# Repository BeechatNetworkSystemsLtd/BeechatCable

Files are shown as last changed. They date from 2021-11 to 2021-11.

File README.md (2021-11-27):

# Beechat Use-&-Charge cable
## _Flexible cable that allows charging your smartphone while using the Beechat Clip_

BNSLTD

General
-------------------

The cable is a UFP (Upstream Facing Port) to DFP (Downstream Facing Port) device, for mobile device charging and data transmission, the DFP port is configured with a 10K resistor between the DC and Vbus pin of the USB-C male plug, which allows a current delivery of up to 3A for devices that require it, the UFP port is designed on a PCB (Printed circuit board), which has the functionality of connecting two FFC (Flexible flat cable) cables, for the transmission of power to the USB-C MALE, also in this design, we have two data transmission lines between the 2 FFC cables, to send and receive data between devices.

Repository content:
-------------------
- Hardware - all Eagle design files (.brd, .sch)
- Production- Gerber files.

Images:
-------------------

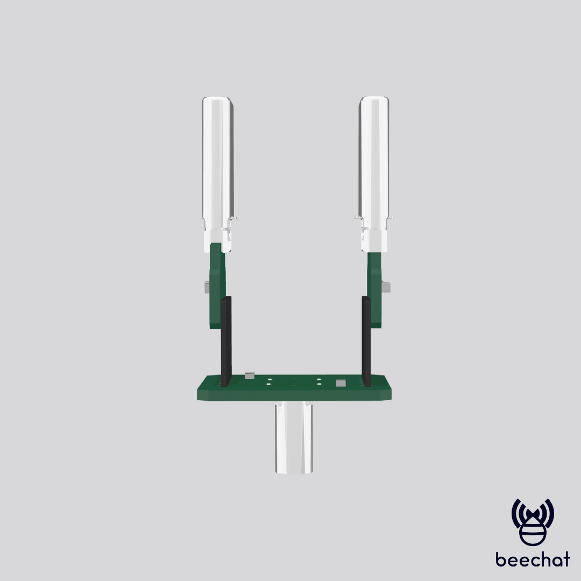
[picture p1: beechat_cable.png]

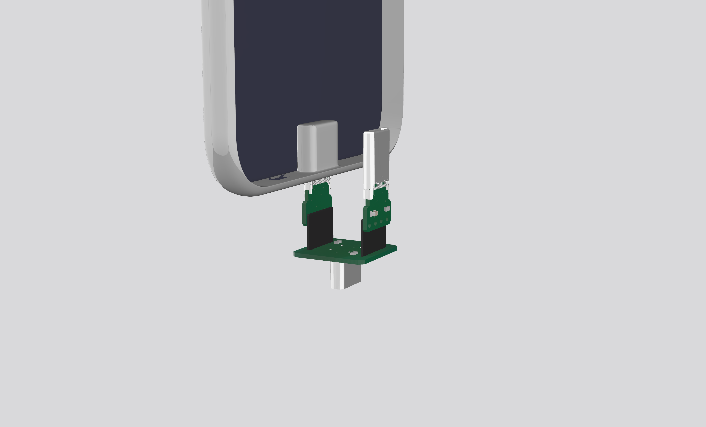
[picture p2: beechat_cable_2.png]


PCB USB-C FEMALE features
-------------------
* **Dimensions:** 14 * 14mm
* **DC resistors:** 5.1 k
* **4-position FFC cable connection pins. (x2)**
* **USB C male receptable connector** 5V (USB)
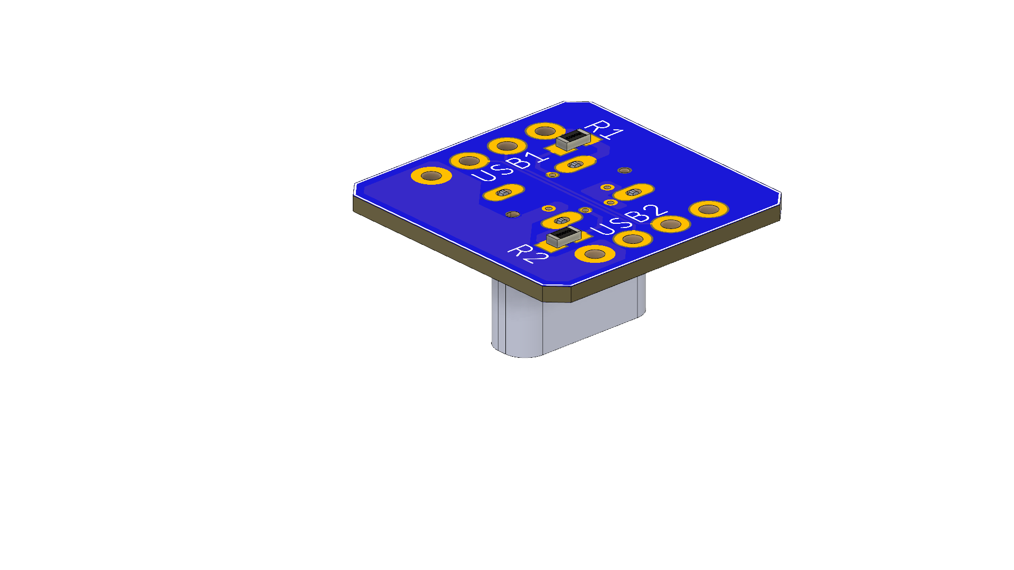
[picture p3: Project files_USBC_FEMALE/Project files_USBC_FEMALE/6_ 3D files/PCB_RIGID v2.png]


PCB USB C MALE features
-------------------
* **Dimensions:** 9.5 * 4mm
* **DC resistor:** 10k
* **4-position FFC cable connection pins. (x1)**
* **USB C Female plug Slim.**
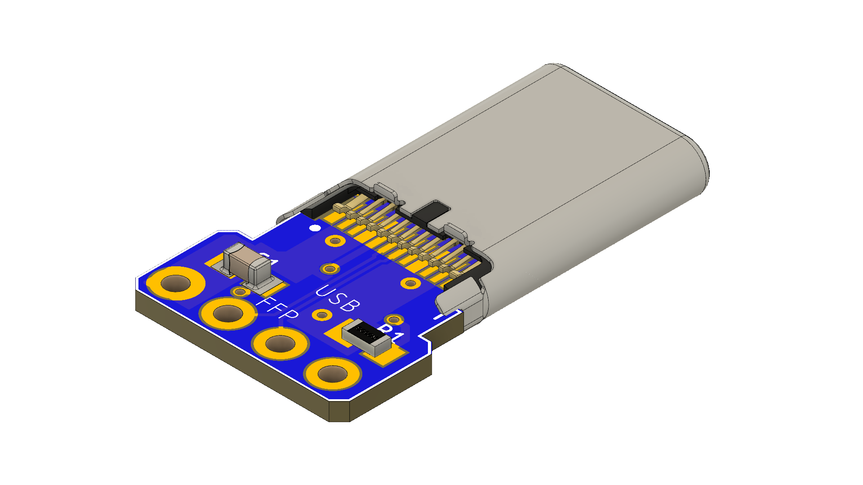
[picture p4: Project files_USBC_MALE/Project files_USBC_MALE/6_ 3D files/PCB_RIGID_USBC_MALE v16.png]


Repository contents:
-------------------
**Project files_USBC_FEMALE:**
- 1_schematics.
- 2_PCB Layout.
- 3_BOM and CPL.
- 4_Gerber files.
- 5_Eagle files.
- 6_3D files.
- 7_Libraries.

**Project files_USBC_MALE:**
- 1_schematics.
- 2_PCB Layout.
- 3_BOM and CPL.
- 4_Gerber files.
- 5_Eagle files.
- 6_3D files.
- 7_Libraries.

Product versions:
-------------------
V1.0 

License Information
-------------------
The hardware is released under [Creative Commons ShareAlike 4.0 International](https://creativecommons.org/licenses/by-sa/4.0/).

Distributed as-is; no warranty is given.

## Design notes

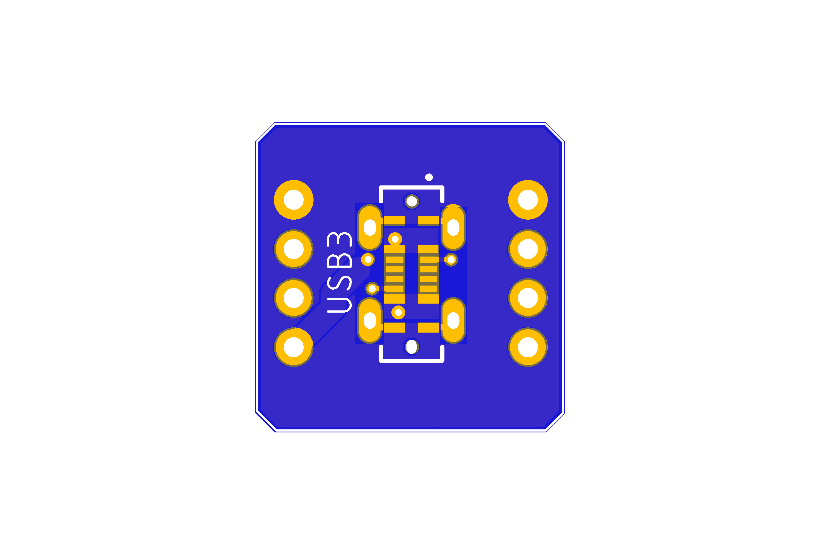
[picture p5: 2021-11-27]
Project files_USBC_FEMALE/Project files_USBC_FEMALE/2_ PCB Layout/PCB_RIGID_BOTTOM.png

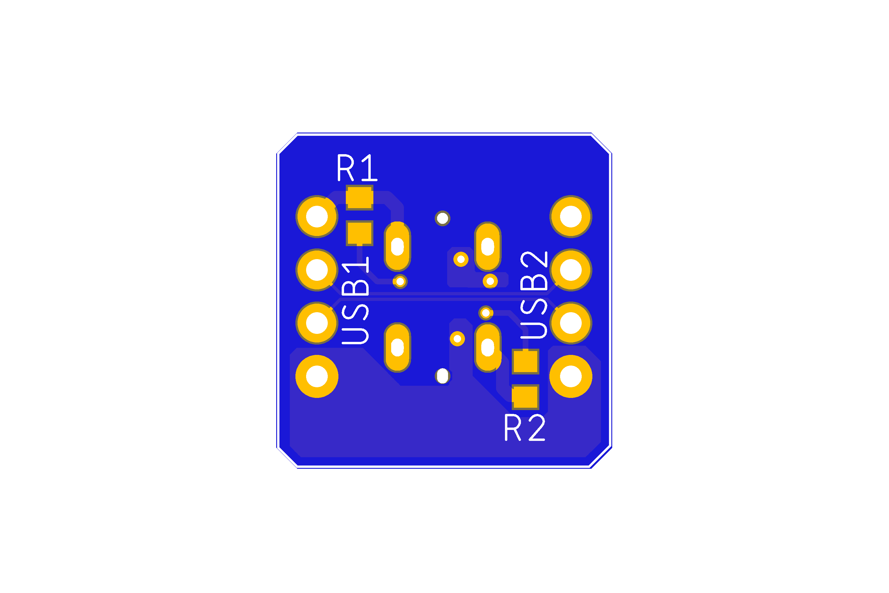
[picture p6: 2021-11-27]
Project files_USBC_FEMALE/Project files_USBC_FEMALE/2_ PCB Layout/PCB_RIGID_TOP.png

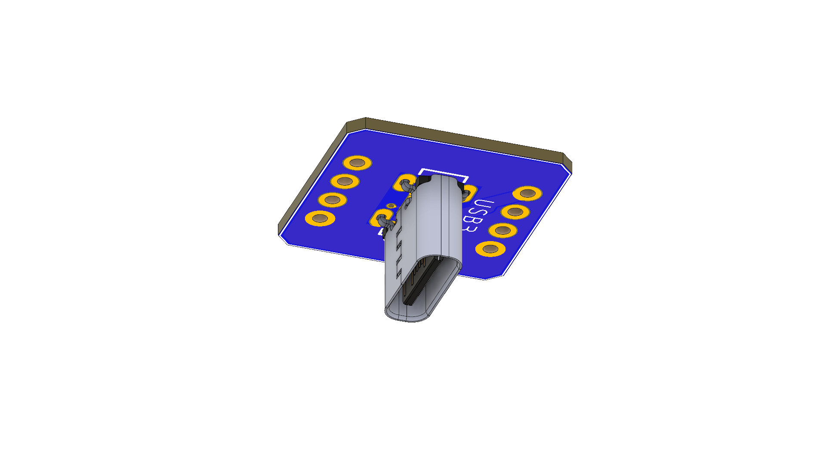
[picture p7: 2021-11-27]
Project files_USBC_FEMALE/Project files_USBC_FEMALE/6_ 3D files/PCB_RIGID v2_2.png

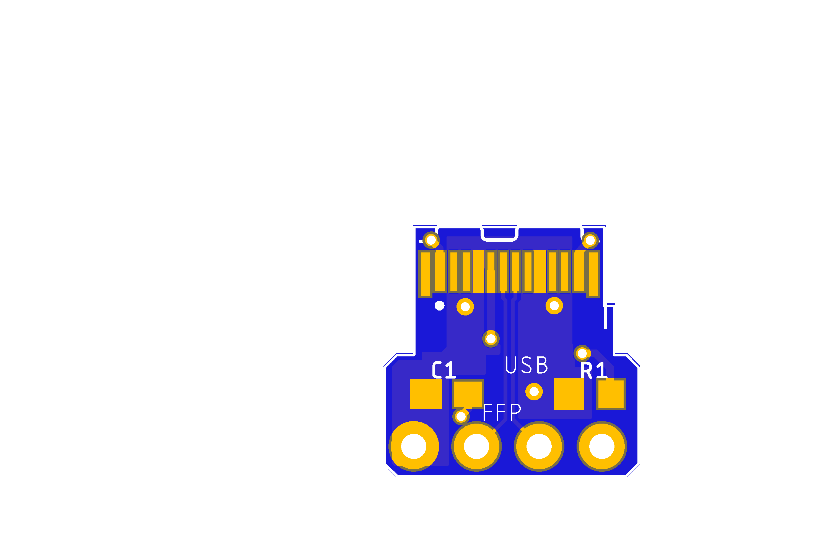
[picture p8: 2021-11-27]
Project files_USBC_MALE/Project files_USBC_MALE/2_ PCB Layout/PCB_RIGID_USBC_MALE_TOP.png

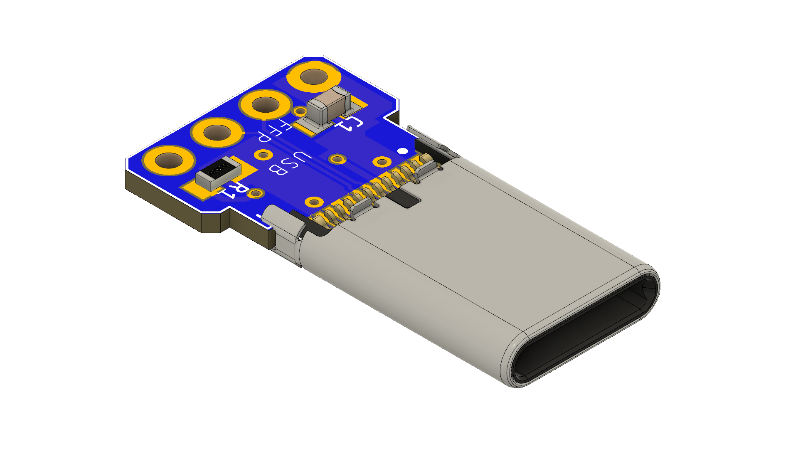
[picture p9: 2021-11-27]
Project files_USBC_MALE/Project files_USBC_MALE/6_ 3D files/PCB_RIGID_USBC_MALE v16_2.png

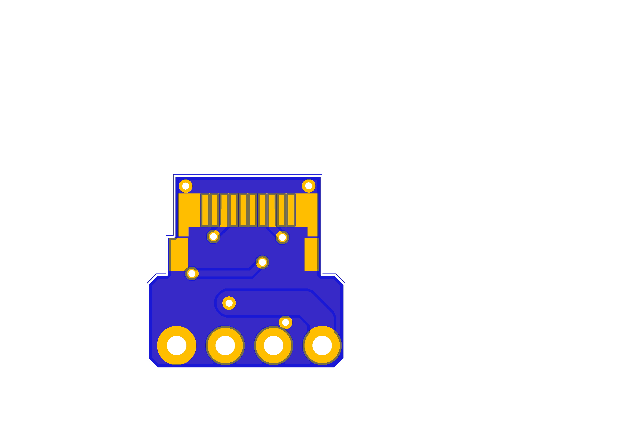
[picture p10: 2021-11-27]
Project files_USBC_MALE/Project files_USBC_MALE/2_ PCB Layout/PCB_RIGID_USBC_MALE_BOTTOM.png

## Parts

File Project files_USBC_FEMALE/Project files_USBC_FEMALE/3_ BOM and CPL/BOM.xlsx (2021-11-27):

 |  |  | BOM
Item # | *Designator | *Qty | Manufacturer | *Mfg Part # | Description / Value | *Package/Footprint | Type | Your Instructions / Notes
1 | R1, R2 | 1 | ROHM Semiconductor (https://ar.mouser.com/manufacturer/rohm-semiconductor/) | ESR03EZPF5101 (https://ar.mouser.com/ProductDetail/ROHM-Semiconductor/ESR03EZPF5101) | 5.1K | C0603 | SMD
2 | USB3 | 1 | GCT (https://ar.mouser.com/manufacturer/gct/) | USB4120-03-C | USB4120-03-C_REVA | GCT_USB4120-03-C_REVA | THT/SMD

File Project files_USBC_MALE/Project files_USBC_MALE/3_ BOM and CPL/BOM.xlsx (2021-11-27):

 |  |  | BOM
Item # | *Designator | *Qty | Manufacturer | *Mfg Part # | Description / Value | *Package/Footprint | Type | Your Instructions / Notes
1 | C1 | 1 | KEMET | C0603C104K3RAC7013 | 100nF | C0603 | SMD
2 | R1 | 1 | ROHM Semiconductor | SFR03EZPF1002 | 10K | R0603 | SMD
3 | DX07P024AJ1R1500 | 1 | JAE Electronics | DX07P024AJ1R1500 | USB | JAE_DX07P024AJ1R1500 | SMD

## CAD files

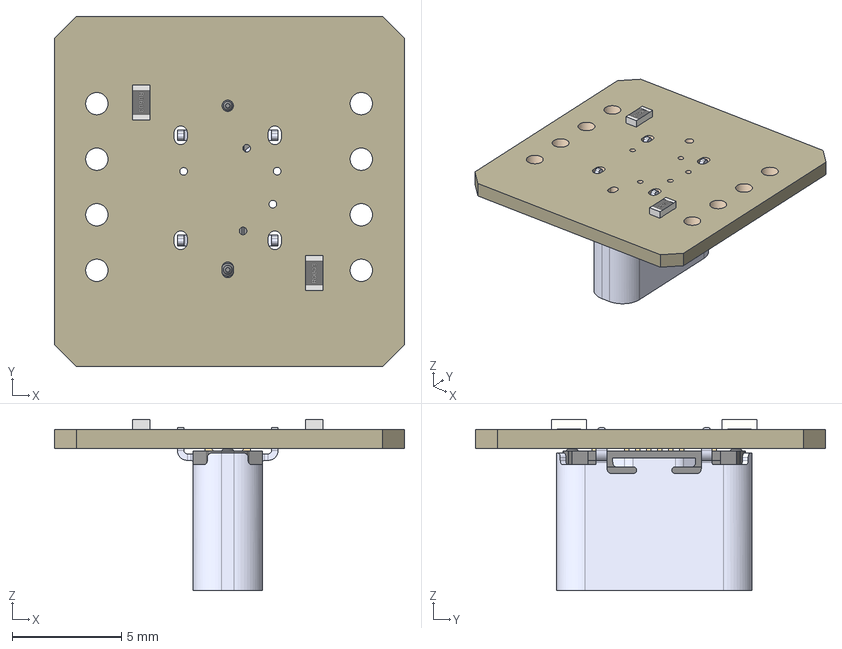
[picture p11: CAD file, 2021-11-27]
Project files_USBC_FEMALE/Project files_USBC_FEMALE/6_ 3D files/PCB_RIGID v2.step
16.0 x 16.0 x 7.82 mm
Board
5.1K x 2
USB4120-03-C_REVA
CONN_FLEX_2.5MM
CONN_FLEX_2.5MM_1

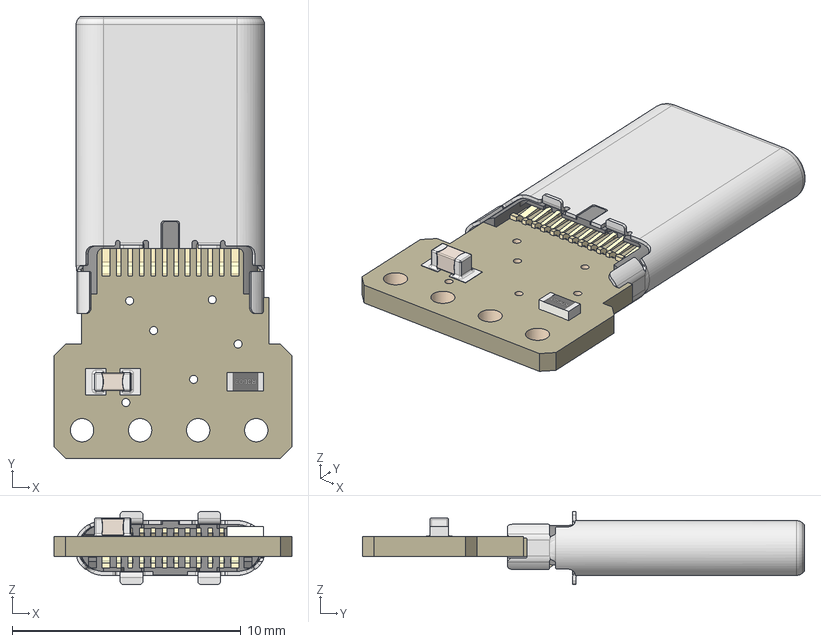
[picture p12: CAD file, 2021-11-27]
Project files_USBC_MALE/Project files_USBC_MALE/6_ 3D files/PCB_RIGID_USBC_MALE v16.step
10.4 x 19.3 x 3.20 mm
Board
Pin1
Pin2
CeramicBody
10k
DX07P024AJ1R1500
CONN_FLEX_2.5MM

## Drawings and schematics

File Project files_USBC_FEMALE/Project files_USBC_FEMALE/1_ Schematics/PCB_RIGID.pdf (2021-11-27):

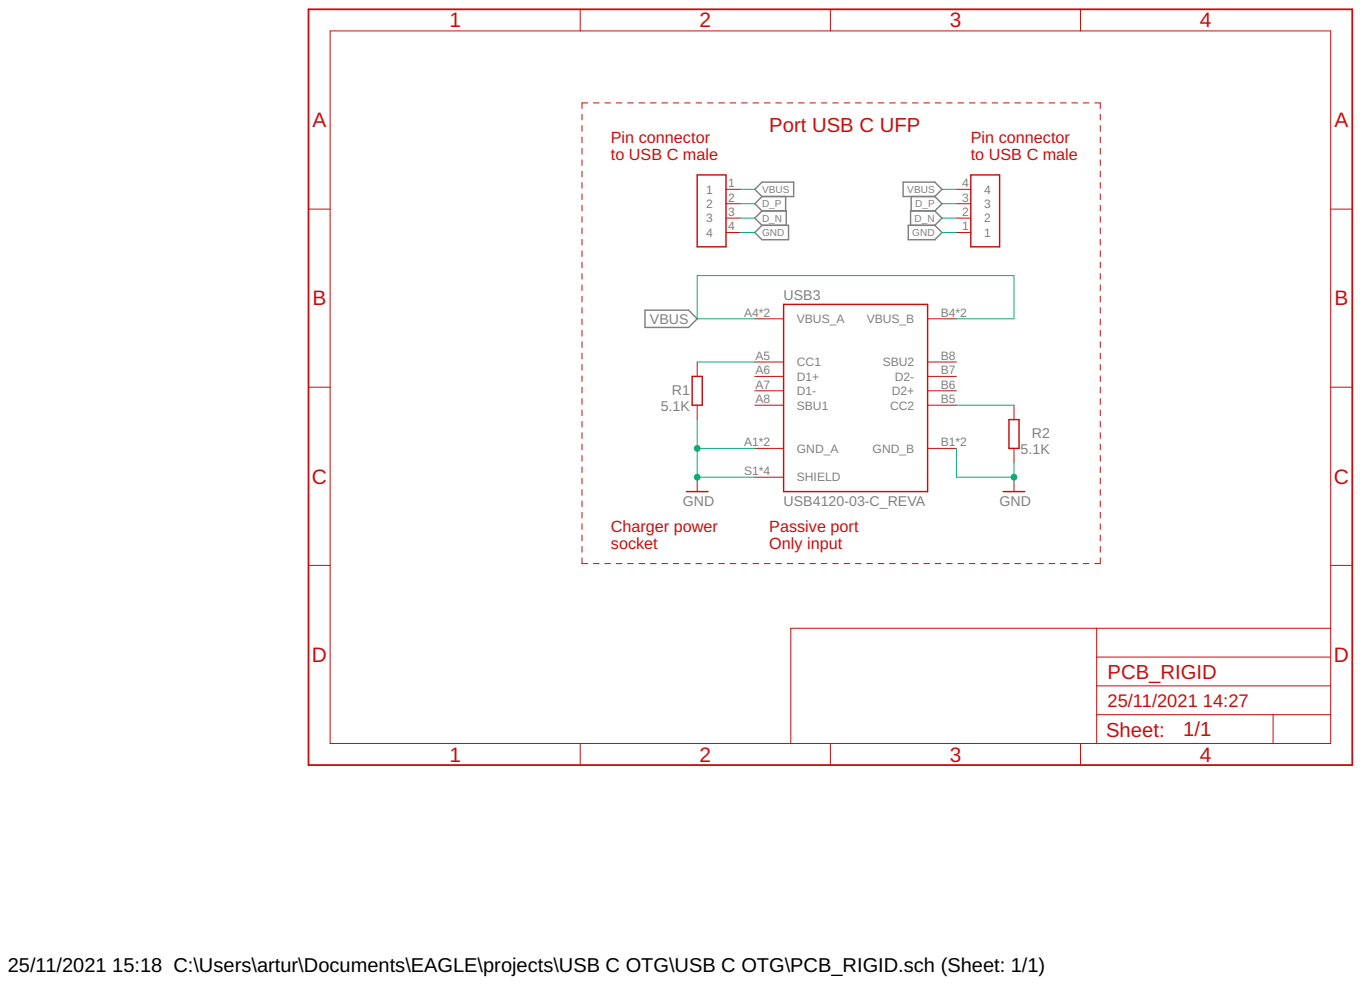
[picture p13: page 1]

25/11/2021 15:18 C:\Users\artur\Documents\EAGLE\projects\USB C OTG\USB C OTG\PCB_RIGID.sch (Sheet: 1/1)

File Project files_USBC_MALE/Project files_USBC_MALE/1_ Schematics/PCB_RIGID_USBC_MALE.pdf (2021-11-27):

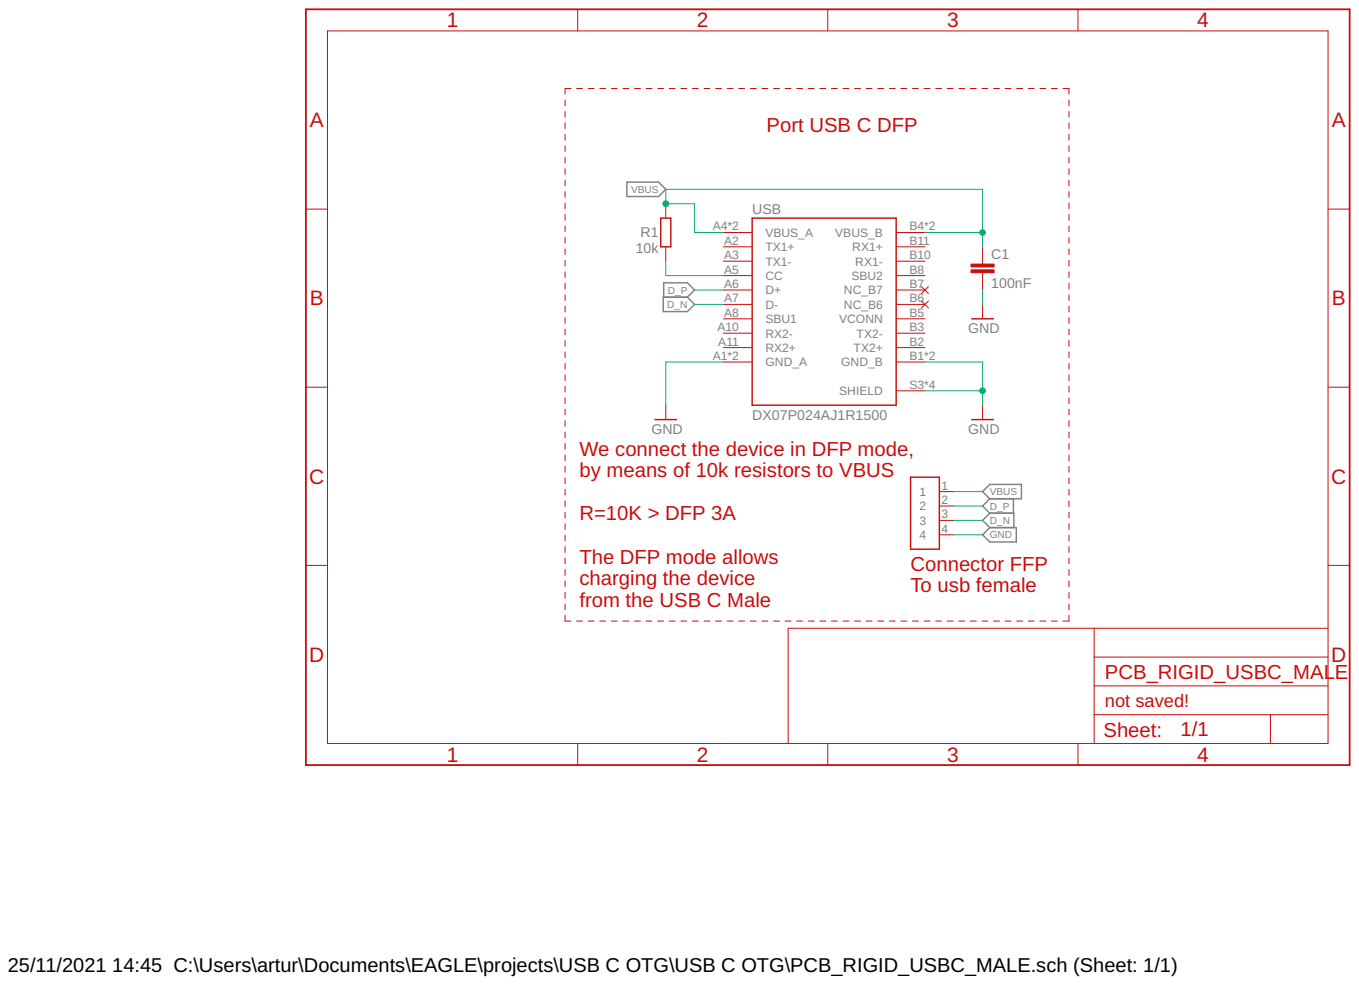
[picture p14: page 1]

We connect the device in DFP mode, by means of 10k resistors to VBUS

The DFP mode allows
charging the device
from the USB C Male

25/11/2021 14:45 C:\Users\artur\Documents\EAGLE\projects\USB C OTG\USB C OTG\PCB_RIGID_USBC_MALE.sch (Sheet: 1/1)

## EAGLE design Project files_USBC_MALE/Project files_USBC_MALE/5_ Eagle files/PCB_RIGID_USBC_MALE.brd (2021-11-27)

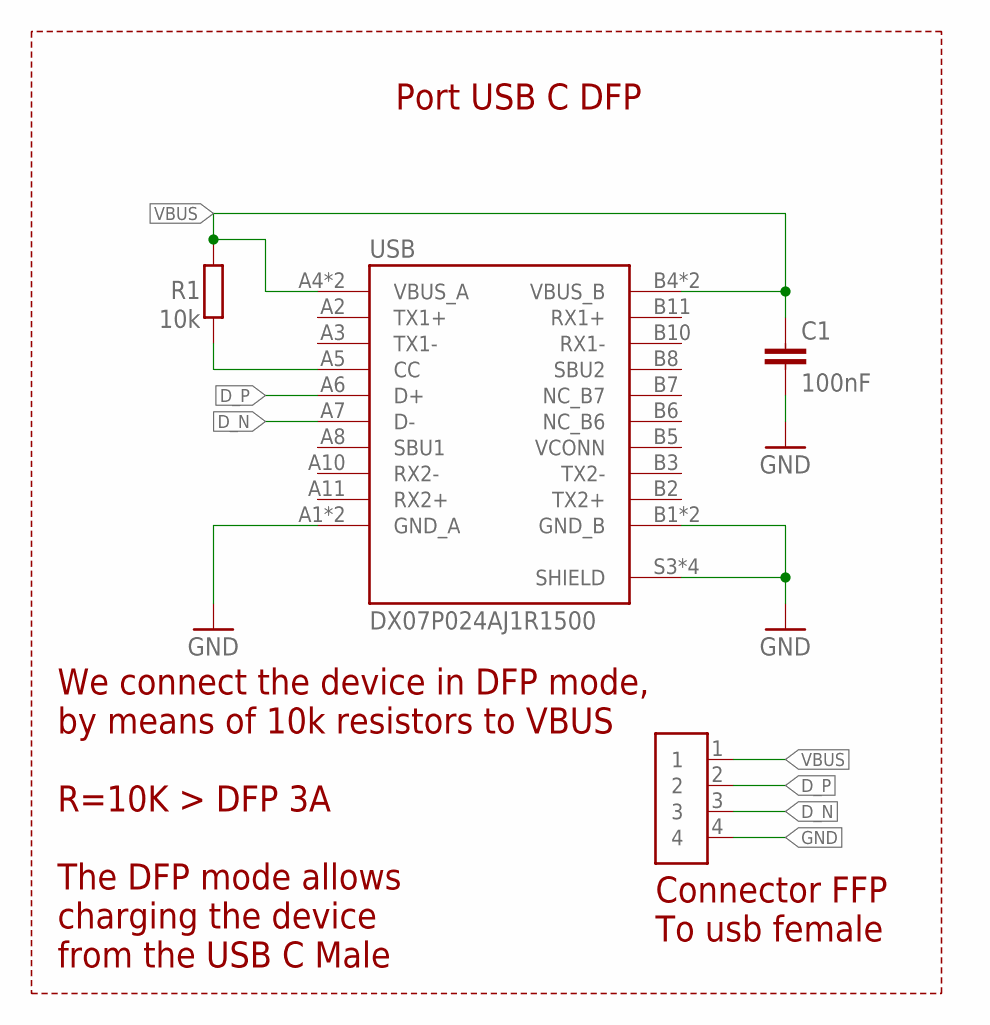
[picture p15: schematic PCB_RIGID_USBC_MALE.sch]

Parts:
C1: 100nF; C0603
FFP: CONN_FLEX_2.5MM
R1: 10k; R0603
USB: DX07P024AJ1R1500; JAE_DX07P024AJ1R1500

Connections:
D_N: FFP.3, USB.A7 (D-)
D_P: FFP.2, USB.A6 (D+)
GND: C1.2, FFP.4, USB.A1 (GND_A), USB.A12 (GND_A), USB.B1 (GND_B), USB.B12 (GND_B), USB.S3 (SHIELD), USB.S4 (SHIELD), USB.S5 (SHIELD), USB.S6 (SHIELD)
unnamed: R1.1, USB.A5 (CC)
VBUS: C1.1, FFP.1, R1.2, USB.A4 (VBUS_A), USB.A9 (VBUS_A), USB.B4 (VBUS_B), USB.B9 (VBUS_B)

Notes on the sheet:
Port USB C DFP
Connector FFP To usb female
We connect the device in DFP mode, by means of 10k resistors to VBUS R=10K > DFP 3A
The DFP mode allows charging the device from the USB C Male

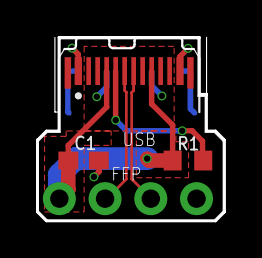
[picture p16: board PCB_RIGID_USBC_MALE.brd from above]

Board: 2 copper layers, 10.4 x 10.2 mm, 4 parts (0 on the bottom side), 5 nets.

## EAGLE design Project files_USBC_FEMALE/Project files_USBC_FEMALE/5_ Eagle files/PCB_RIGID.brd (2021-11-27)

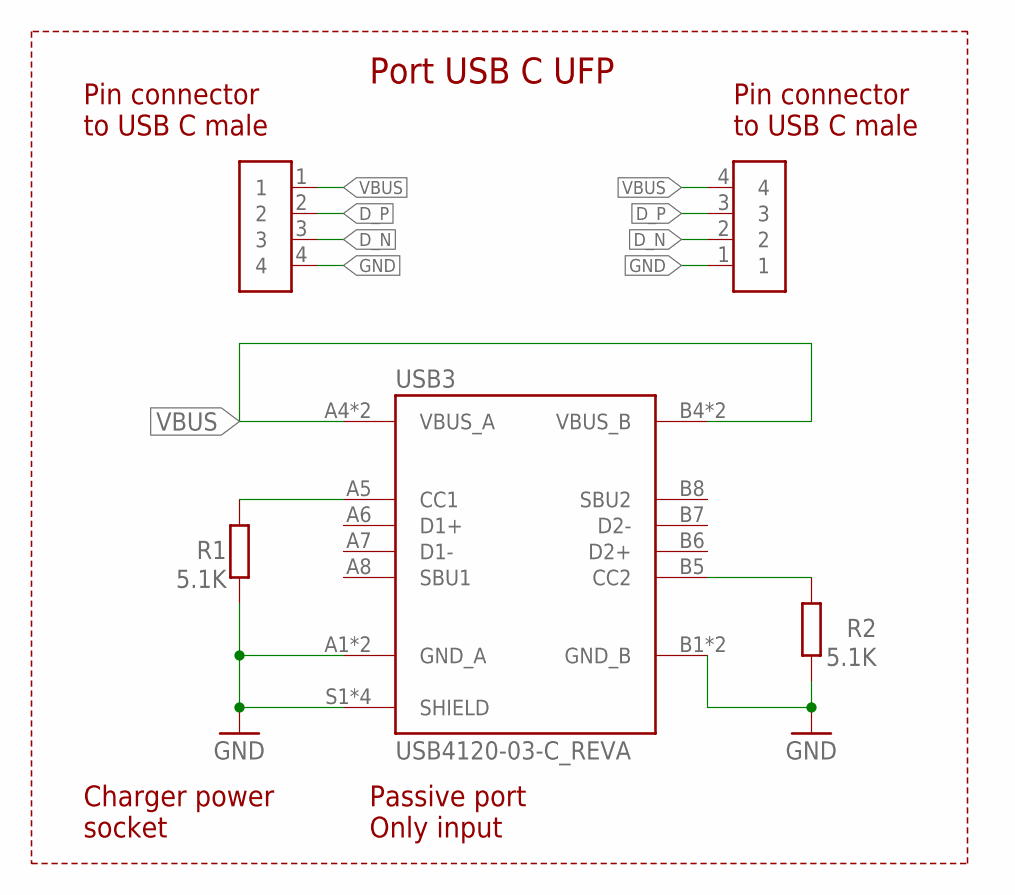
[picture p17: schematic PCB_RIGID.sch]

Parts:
R1, R2: 5.1K; R0603
USB1, USB2: CONN_FLEX_2.5MM
USB3: USB4120-03-C_REVA; GCT_USB4120-03-C_REVA

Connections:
D_N: USB1.3, USB2.2
D_P: USB1.2, USB2.3
GND: R1.1, R2.1, USB1.4, USB2.1, USB3.A1 (GND_A), USB3.A12 (GND_A), USB3.B1 (GND_B), USB3.B12 (GND_B), USB3.S1 (SHIELD), USB3.S2 (SHIELD), USB3.S3 (SHIELD), USB3.S4 (SHIELD)
unnamed: R1.2, USB3.A5 (CC1)
unnamed: R2.2, USB3.B5 (CC2)
VBUS: USB1.1, USB2.4, USB3.A4 (VBUS_A), USB3.A9 (VBUS_A), USB3.B4 (VBUS_B), USB3.B9 (VBUS_B)

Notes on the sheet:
Port USB C UFP
Passive port Only input
Charger power socket
Pin connector to USB C male

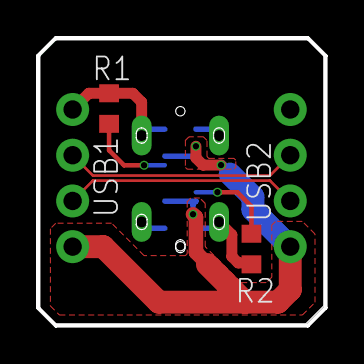
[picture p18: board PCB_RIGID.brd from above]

Board: 2 copper layers, 16.0 x 16.0 mm, 5 parts (1 on the bottom side), 6 nets.
